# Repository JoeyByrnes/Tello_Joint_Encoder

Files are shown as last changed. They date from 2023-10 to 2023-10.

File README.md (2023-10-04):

# Tello_Joint_Encoder
PCB Design Files and Firmware for Tello Joint Encoders

<p align="center">
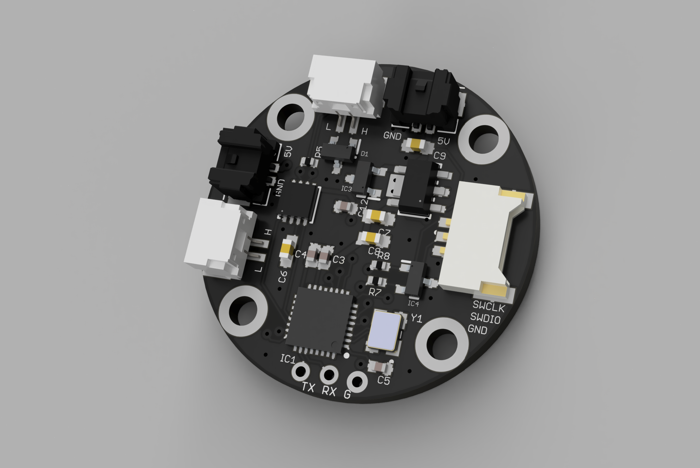
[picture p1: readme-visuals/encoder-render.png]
  
</p>
<p align="center">
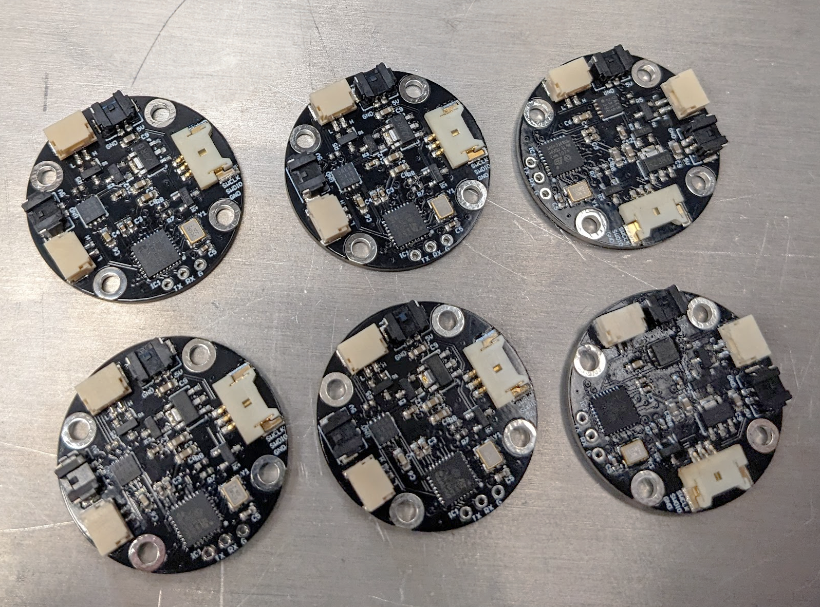
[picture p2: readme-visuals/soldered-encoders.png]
  
</p>
<p align="center">
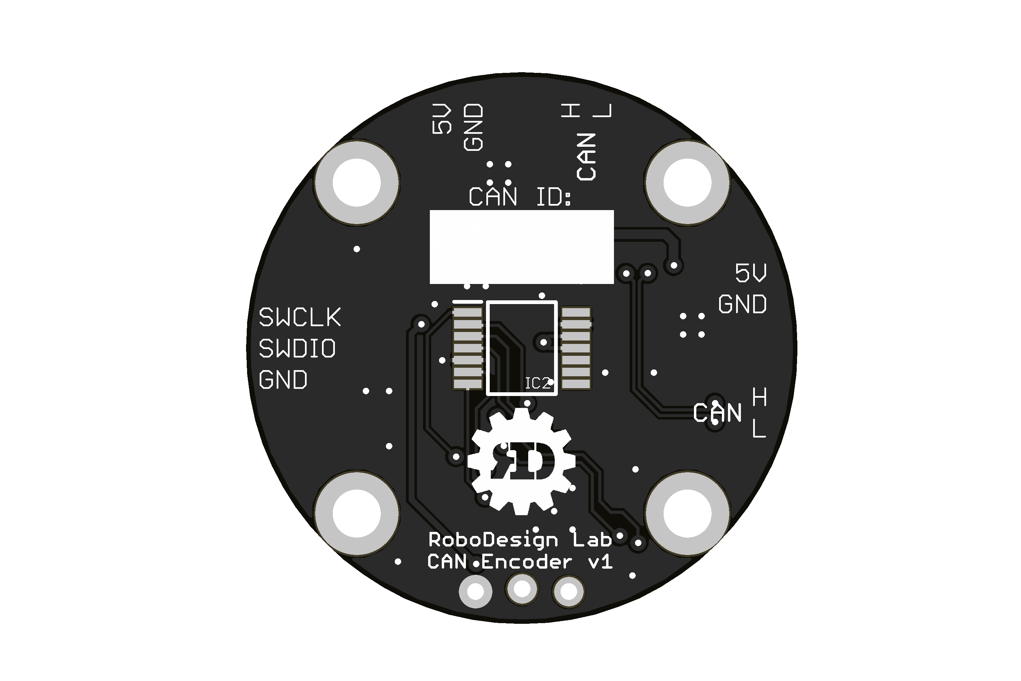
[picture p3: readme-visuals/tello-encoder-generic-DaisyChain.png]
  
</p>
<p align="center">
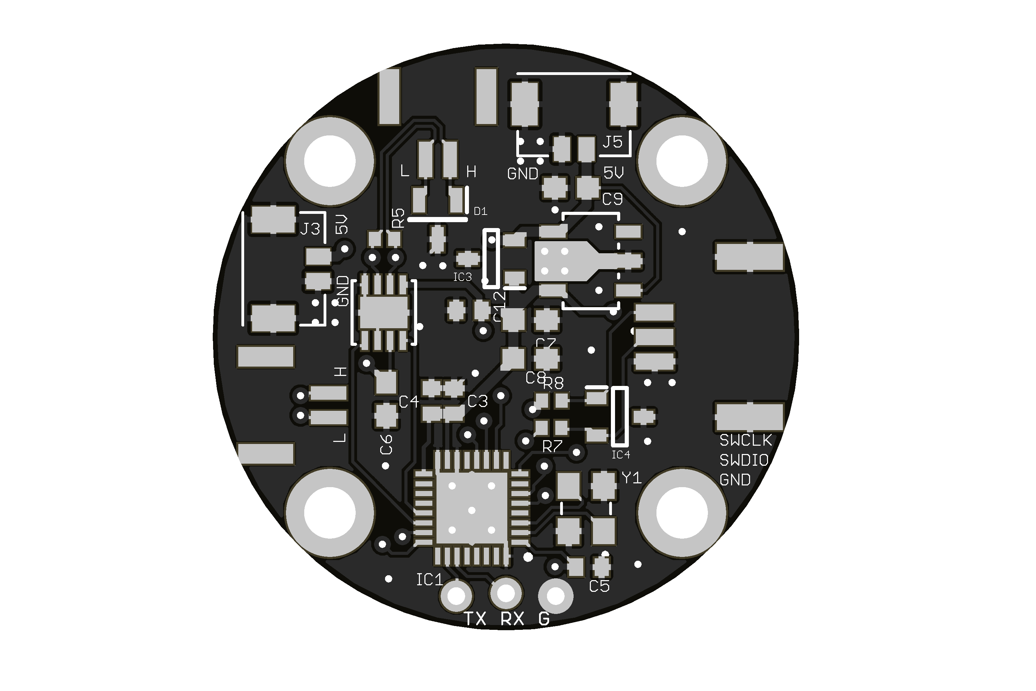
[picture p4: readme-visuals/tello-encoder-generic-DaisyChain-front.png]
  
</p>
<p align="center">
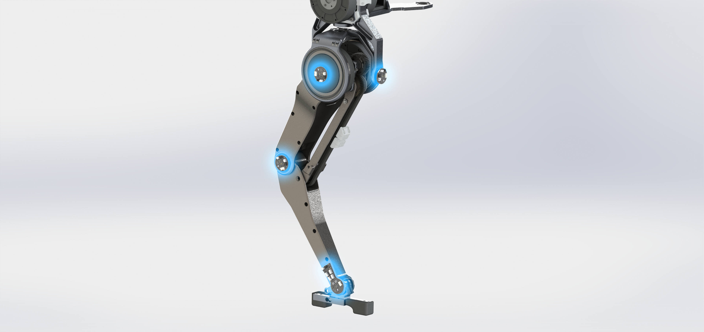
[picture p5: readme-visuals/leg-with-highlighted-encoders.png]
  
</p>

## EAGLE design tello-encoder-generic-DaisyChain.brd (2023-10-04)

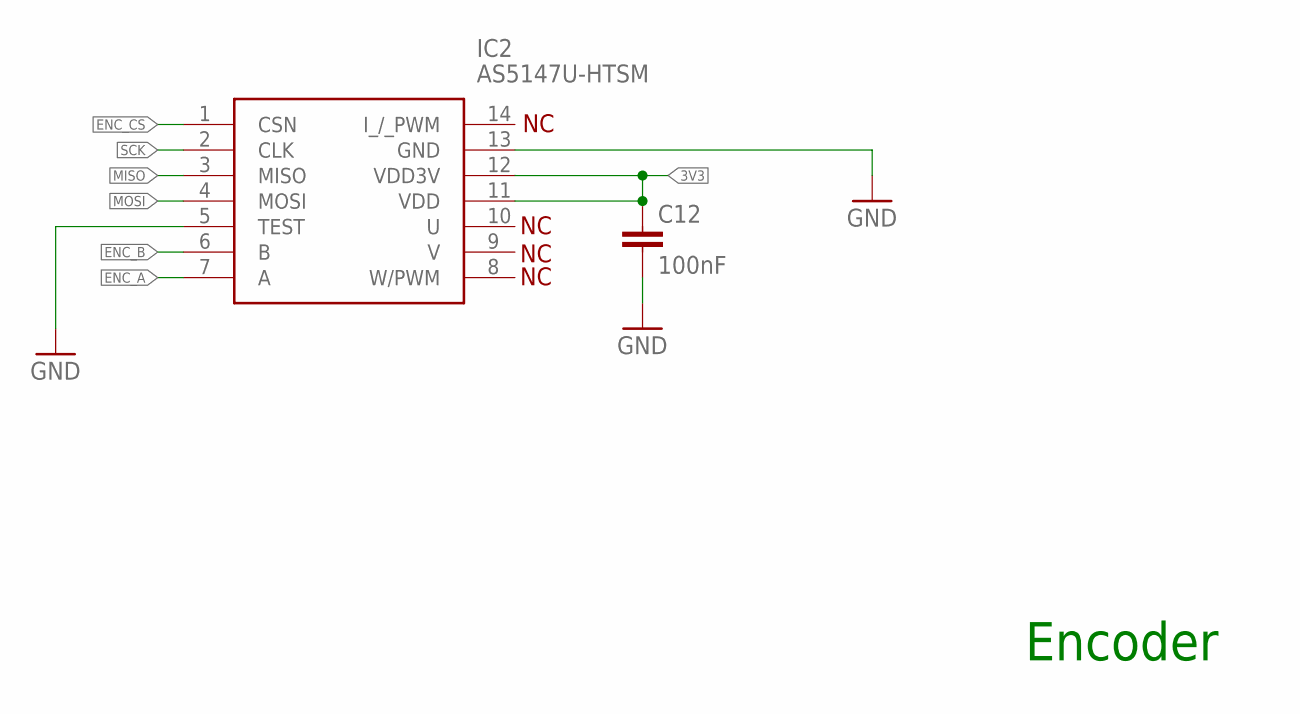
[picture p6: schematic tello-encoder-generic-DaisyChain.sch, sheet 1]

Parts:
C12: 100nF; C0402
IC2: AS5147U-HTSM; SOP65P640X120-14N

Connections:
3V3: C12.1, IC2.11 (VDD), IC2.12 (VDD3V); also elsewhere on the board
ENC_A: IC2.7 (A); also elsewhere on the board
ENC_B: IC2.6 (B); also elsewhere on the board
ENC_CS: IC2.1 (CSN); also elsewhere on the board
GND: C12.2, IC2.5 (TEST), IC2.13 (GND); also elsewhere on the board
MISO: IC2.3 (MISO); also elsewhere on the board
MOSI: IC2.4 (MOSI); also elsewhere on the board
SCK: IC2.2 (CLK); also elsewhere on the board

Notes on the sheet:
Encoder

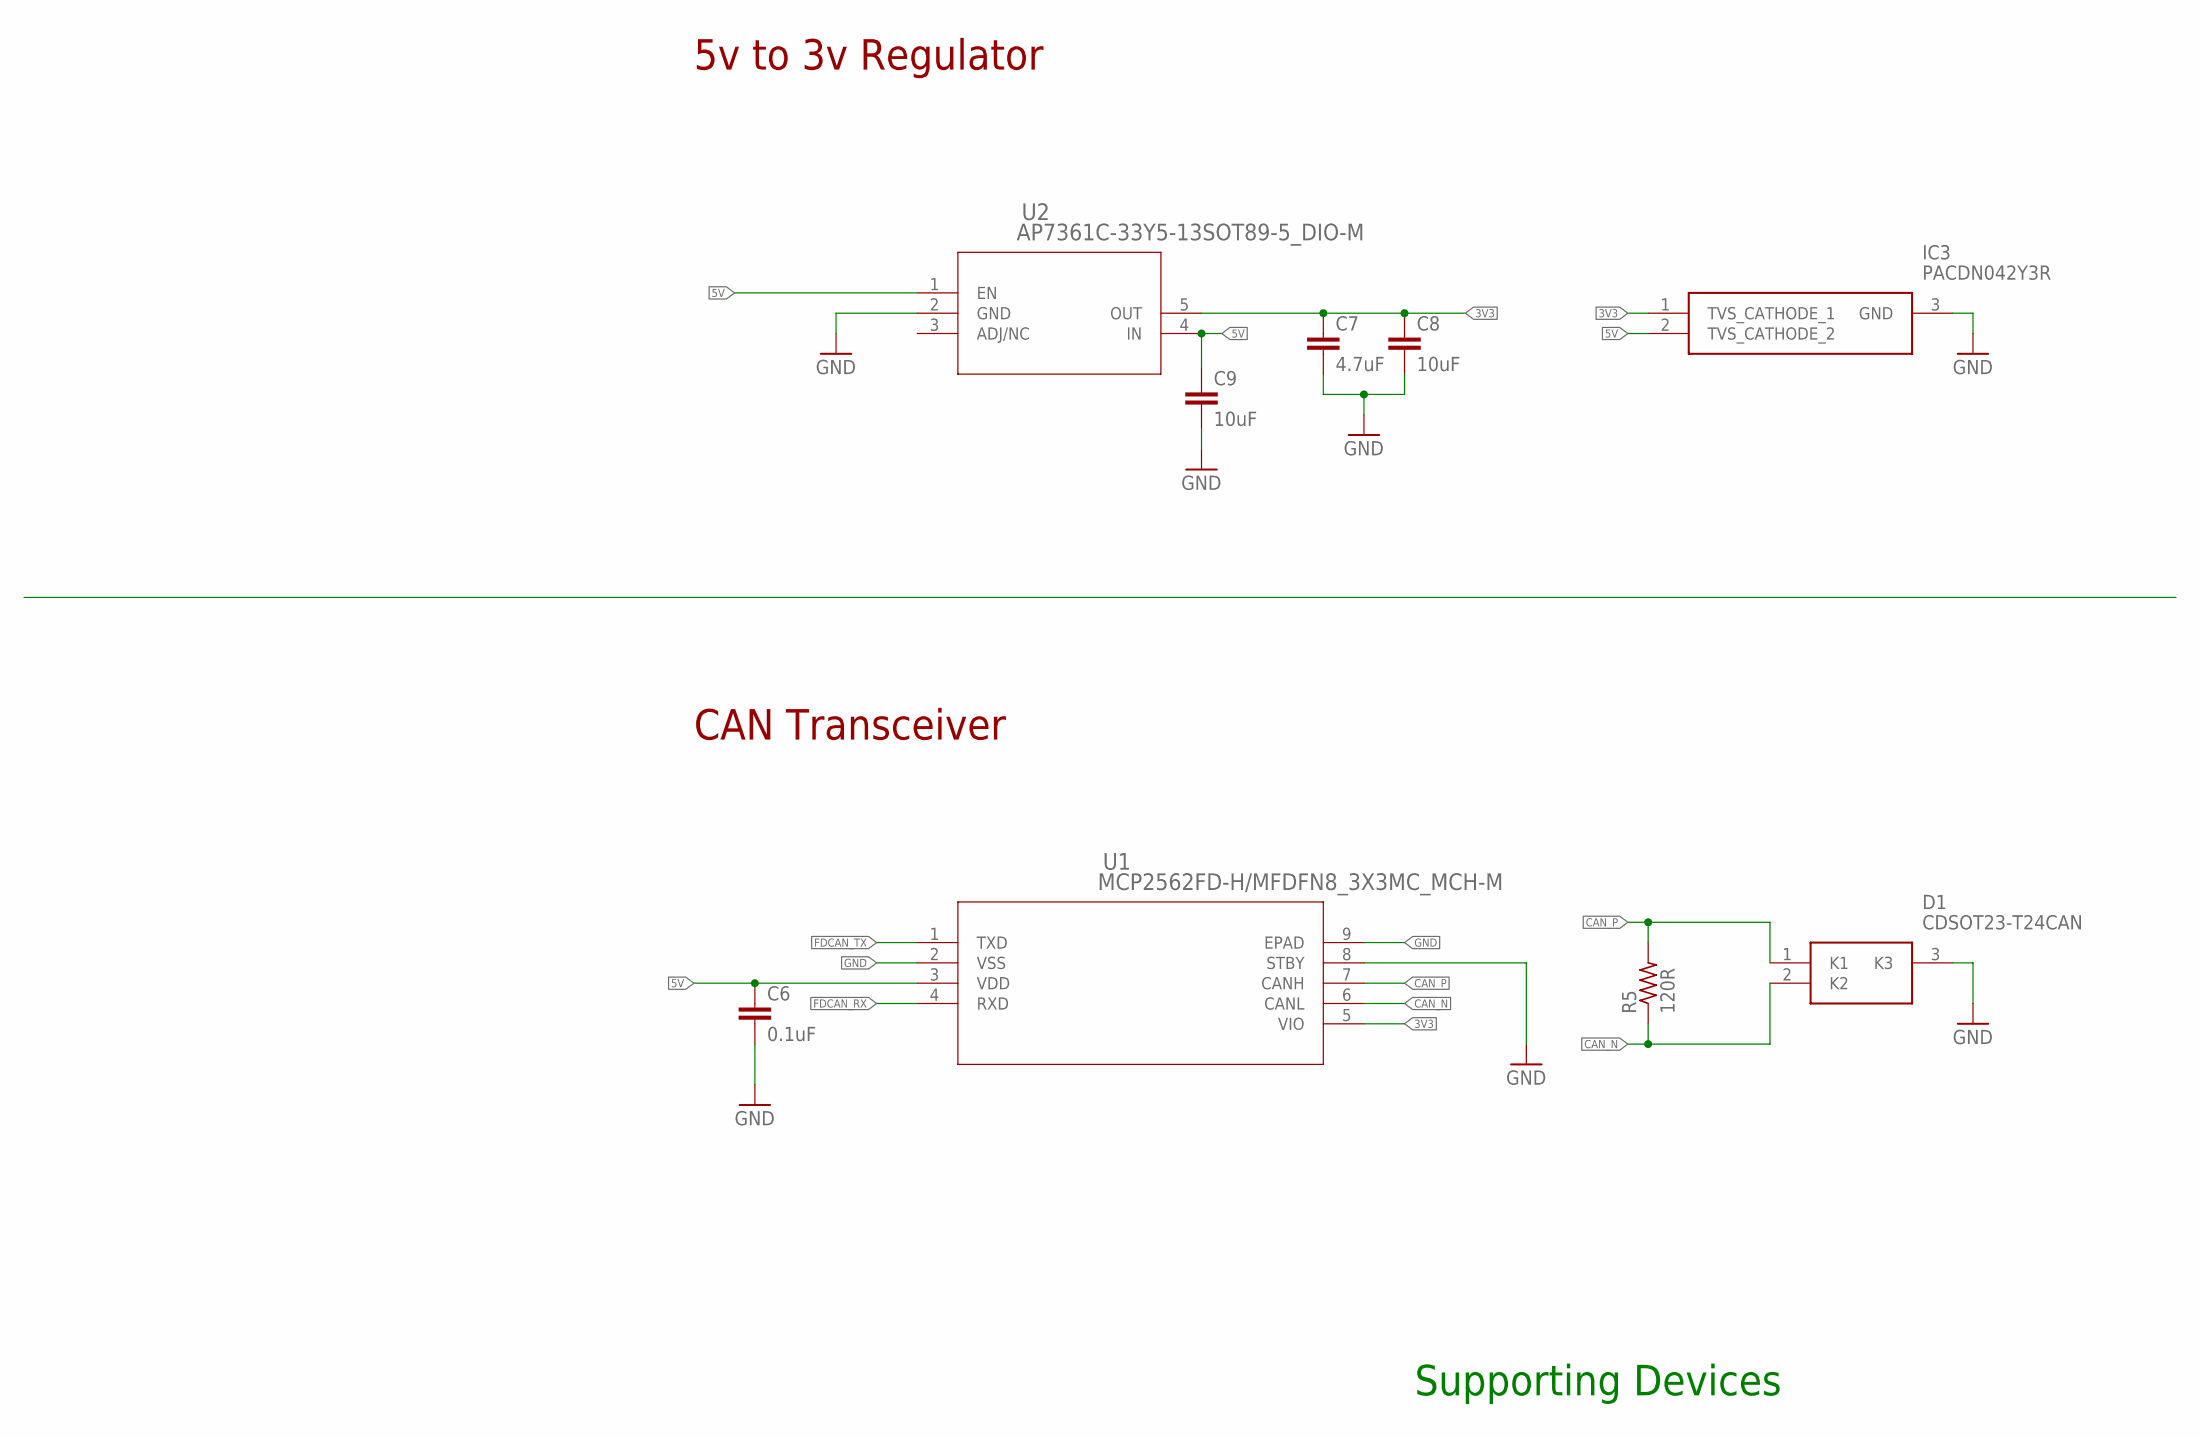
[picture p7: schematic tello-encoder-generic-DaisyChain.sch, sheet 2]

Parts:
C6: 0.1uF; C0603
C7: 4.7uF; C0603
C8, C9: 10uF; C0603
D1: CDSOT23-T24CAN; SOT95P230X117-3N
IC3: PACDN042Y3R; SOT96P237X111-3N
R5: 120R; R0402
U1: MCP2562FD-H/MFDFN8_3X3MC_MCH-M; DFN8_3X3MC_MCH-M
U2: AP7361C-33Y5-13SOT89-5_DIO-M; SOT89-5_DIO-M

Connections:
3V3: C7.1, C8.1, IC3.1 (TVS_CATHODE_1), U1.5 (VIO), U2.5 (OUT); also elsewhere on the board
5V: C6.1, C9.1, IC3.2 (TVS_CATHODE_2), U1.3 (VDD), U2.1 (EN), U2.4 (IN); also elsewhere on the board
CAN_N: D1.2 (K2), R5.1, U1.6 (CANL); also elsewhere on the board
CAN_P: D1.1 (K1), R5.2, U1.7 (CANH); also elsewhere on the board
FDCAN_RX: U1.4 (RXD); also elsewhere on the board
FDCAN_TX: U1.1 (TXD); also elsewhere on the board
GND: C6.2, C7.2, C8.2, C9.2, D1.3 (K3), IC3.3 (GND), U1.2 (VSS), U1.8 (STBY), U1.9 (EPAD), U2.2 (GND); also elsewhere on the board

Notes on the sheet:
5v to 3v Regulator
CAN Transceiver
Supporting Devices

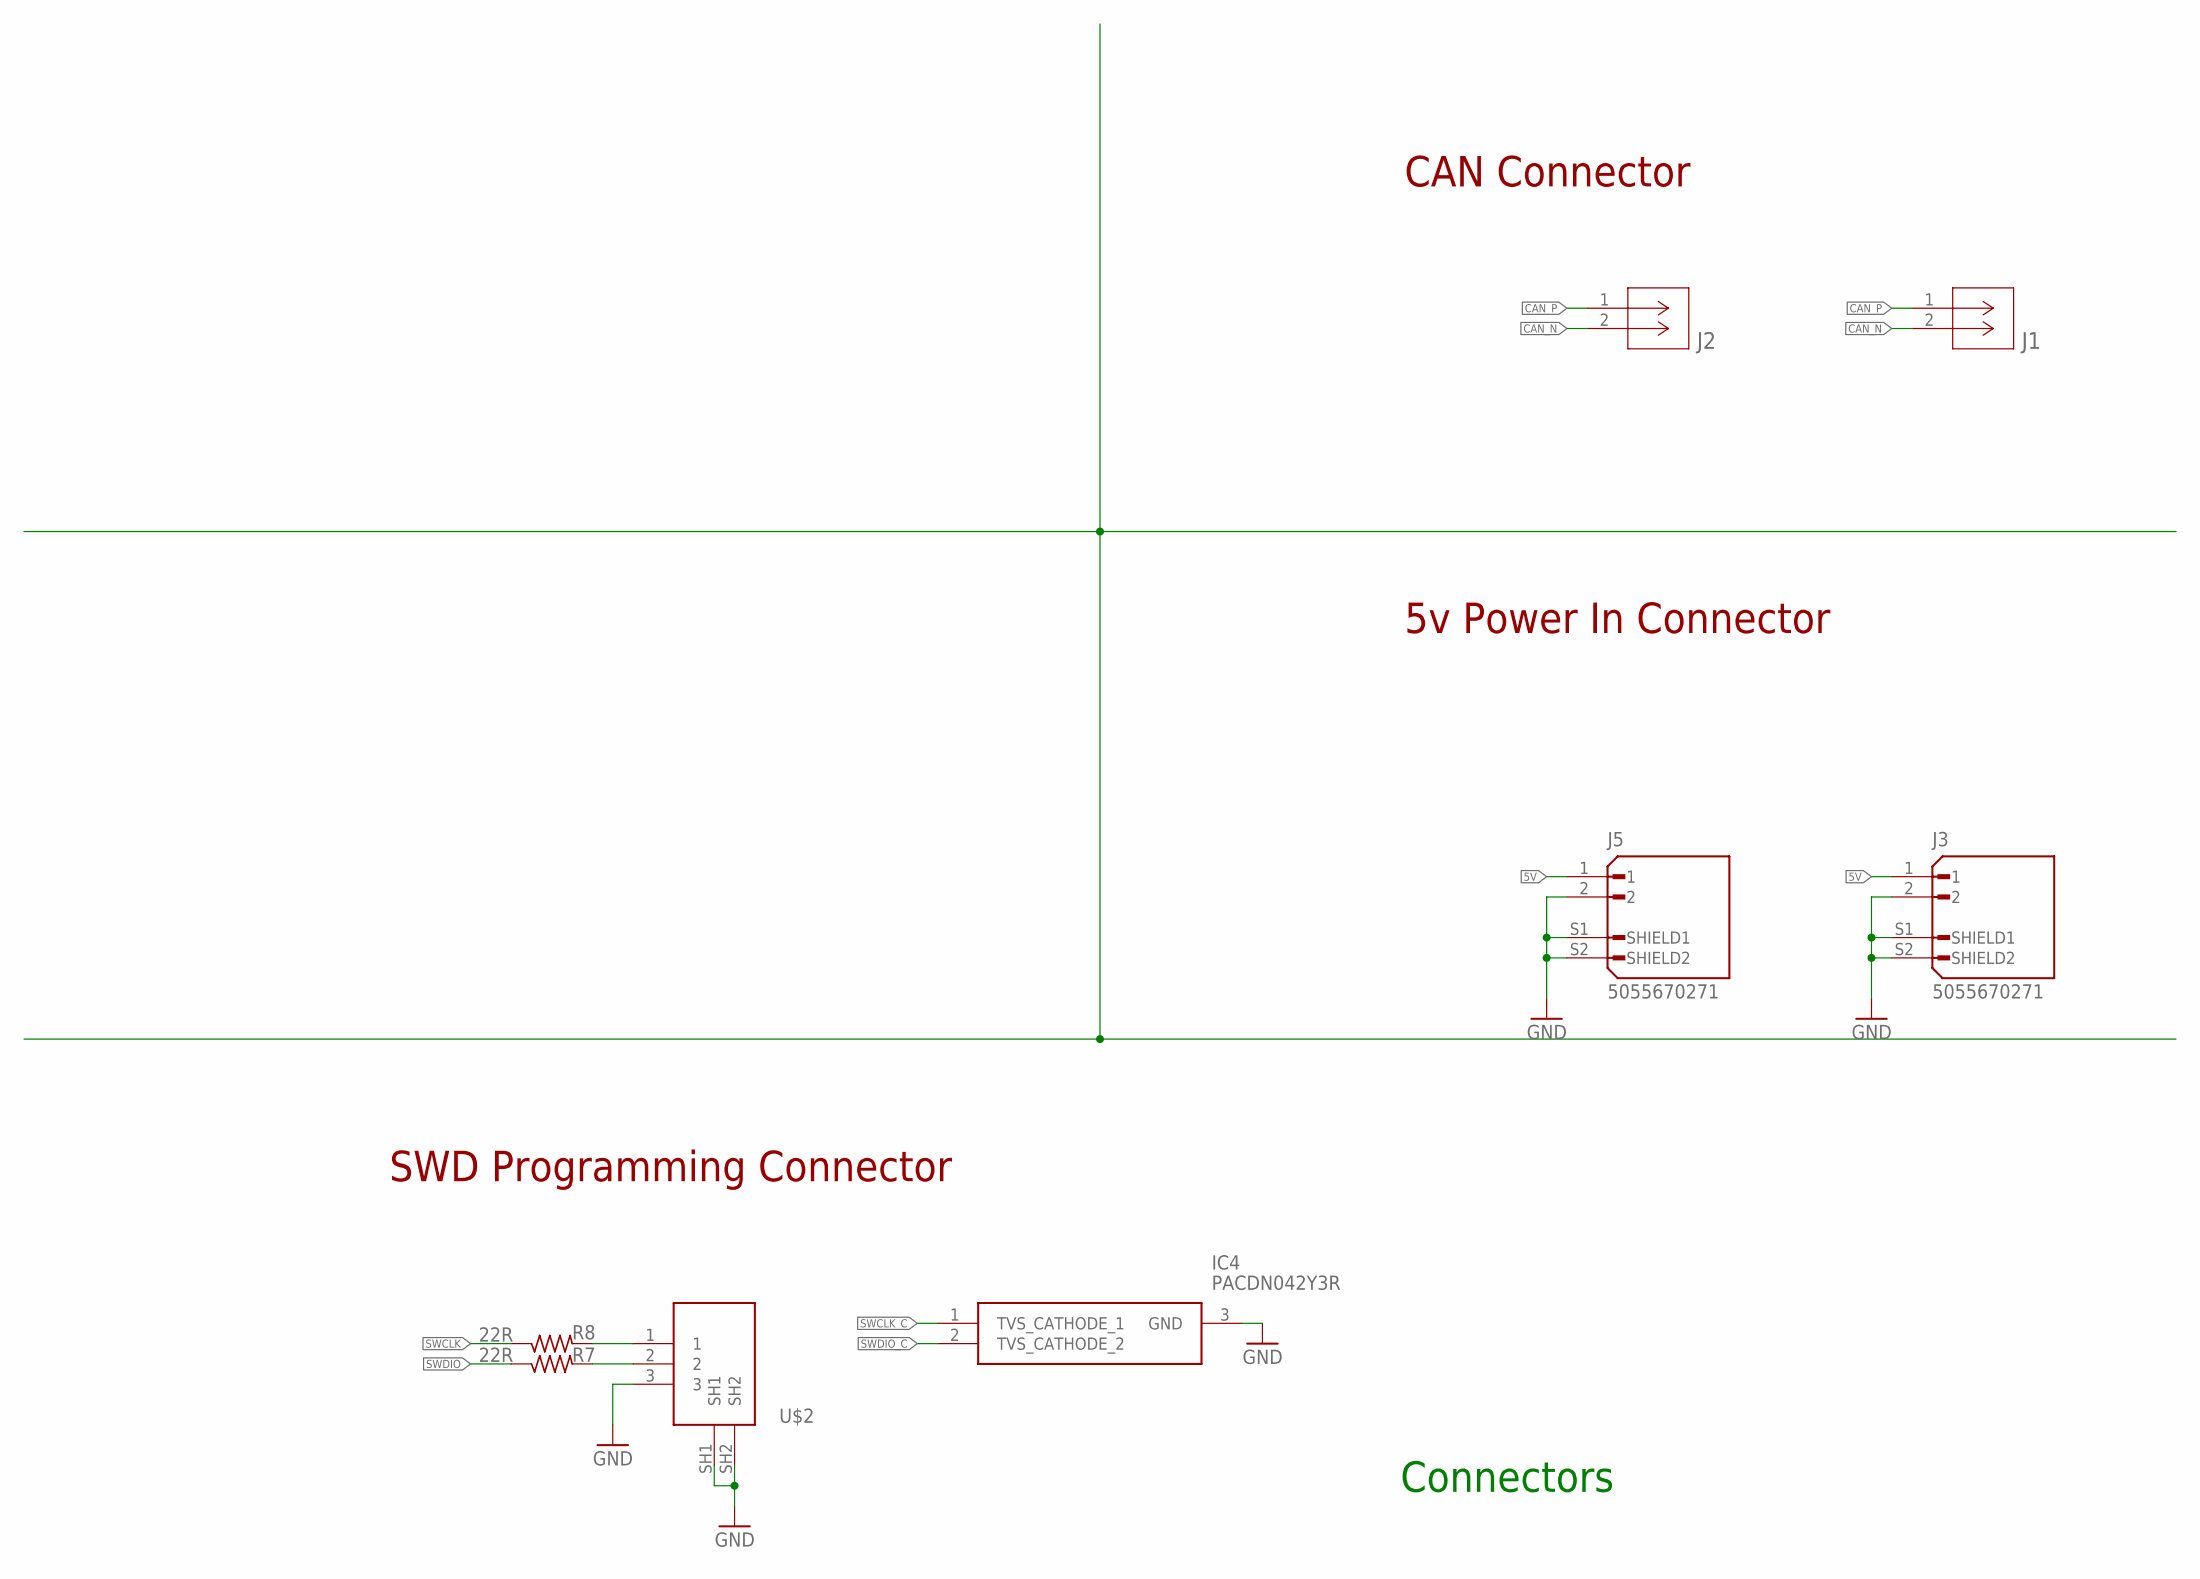
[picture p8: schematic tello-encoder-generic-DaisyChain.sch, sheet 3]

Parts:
IC4: PACDN042Y3R; SOT96P237X111-3N
J1, J2: SM02BGHSTBLFSN; CONN_SM02BGHSTB_JST
J3, J5: 5055670271; MOLEX_5055670271
R7, R8: 22R; R0402
U$2: 125SH-G-03-TR-SMT

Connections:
5V: J3.1, J5.1; also elsewhere on the board
CAN_N: J1.2, J2.2; also elsewhere on the board
CAN_P: J1.1, J2.1; also elsewhere on the board
GND: IC4.3 (GND), J3.2, J3.S1 (SHIELD1), J3.S2 (SHIELD2), J5.2, J5.S1 (SHIELD1), J5.S2 (SHIELD2), U$2.3, U$2.SH1, U$2.SH2; also elsewhere on the board
SWCLK: R8.1; also elsewhere on the board
SWCLK_C: IC4.1 (TVS_CATHODE_1), R8.2, U$2.1
SWDIO: R7.1; also elsewhere on the board
SWDIO_C: IC4.2 (TVS_CATHODE_2), R7.2, U$2.2

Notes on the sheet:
U$2
CAN Connector
5v Power In Connector
SWD Programming Connector
Connectors

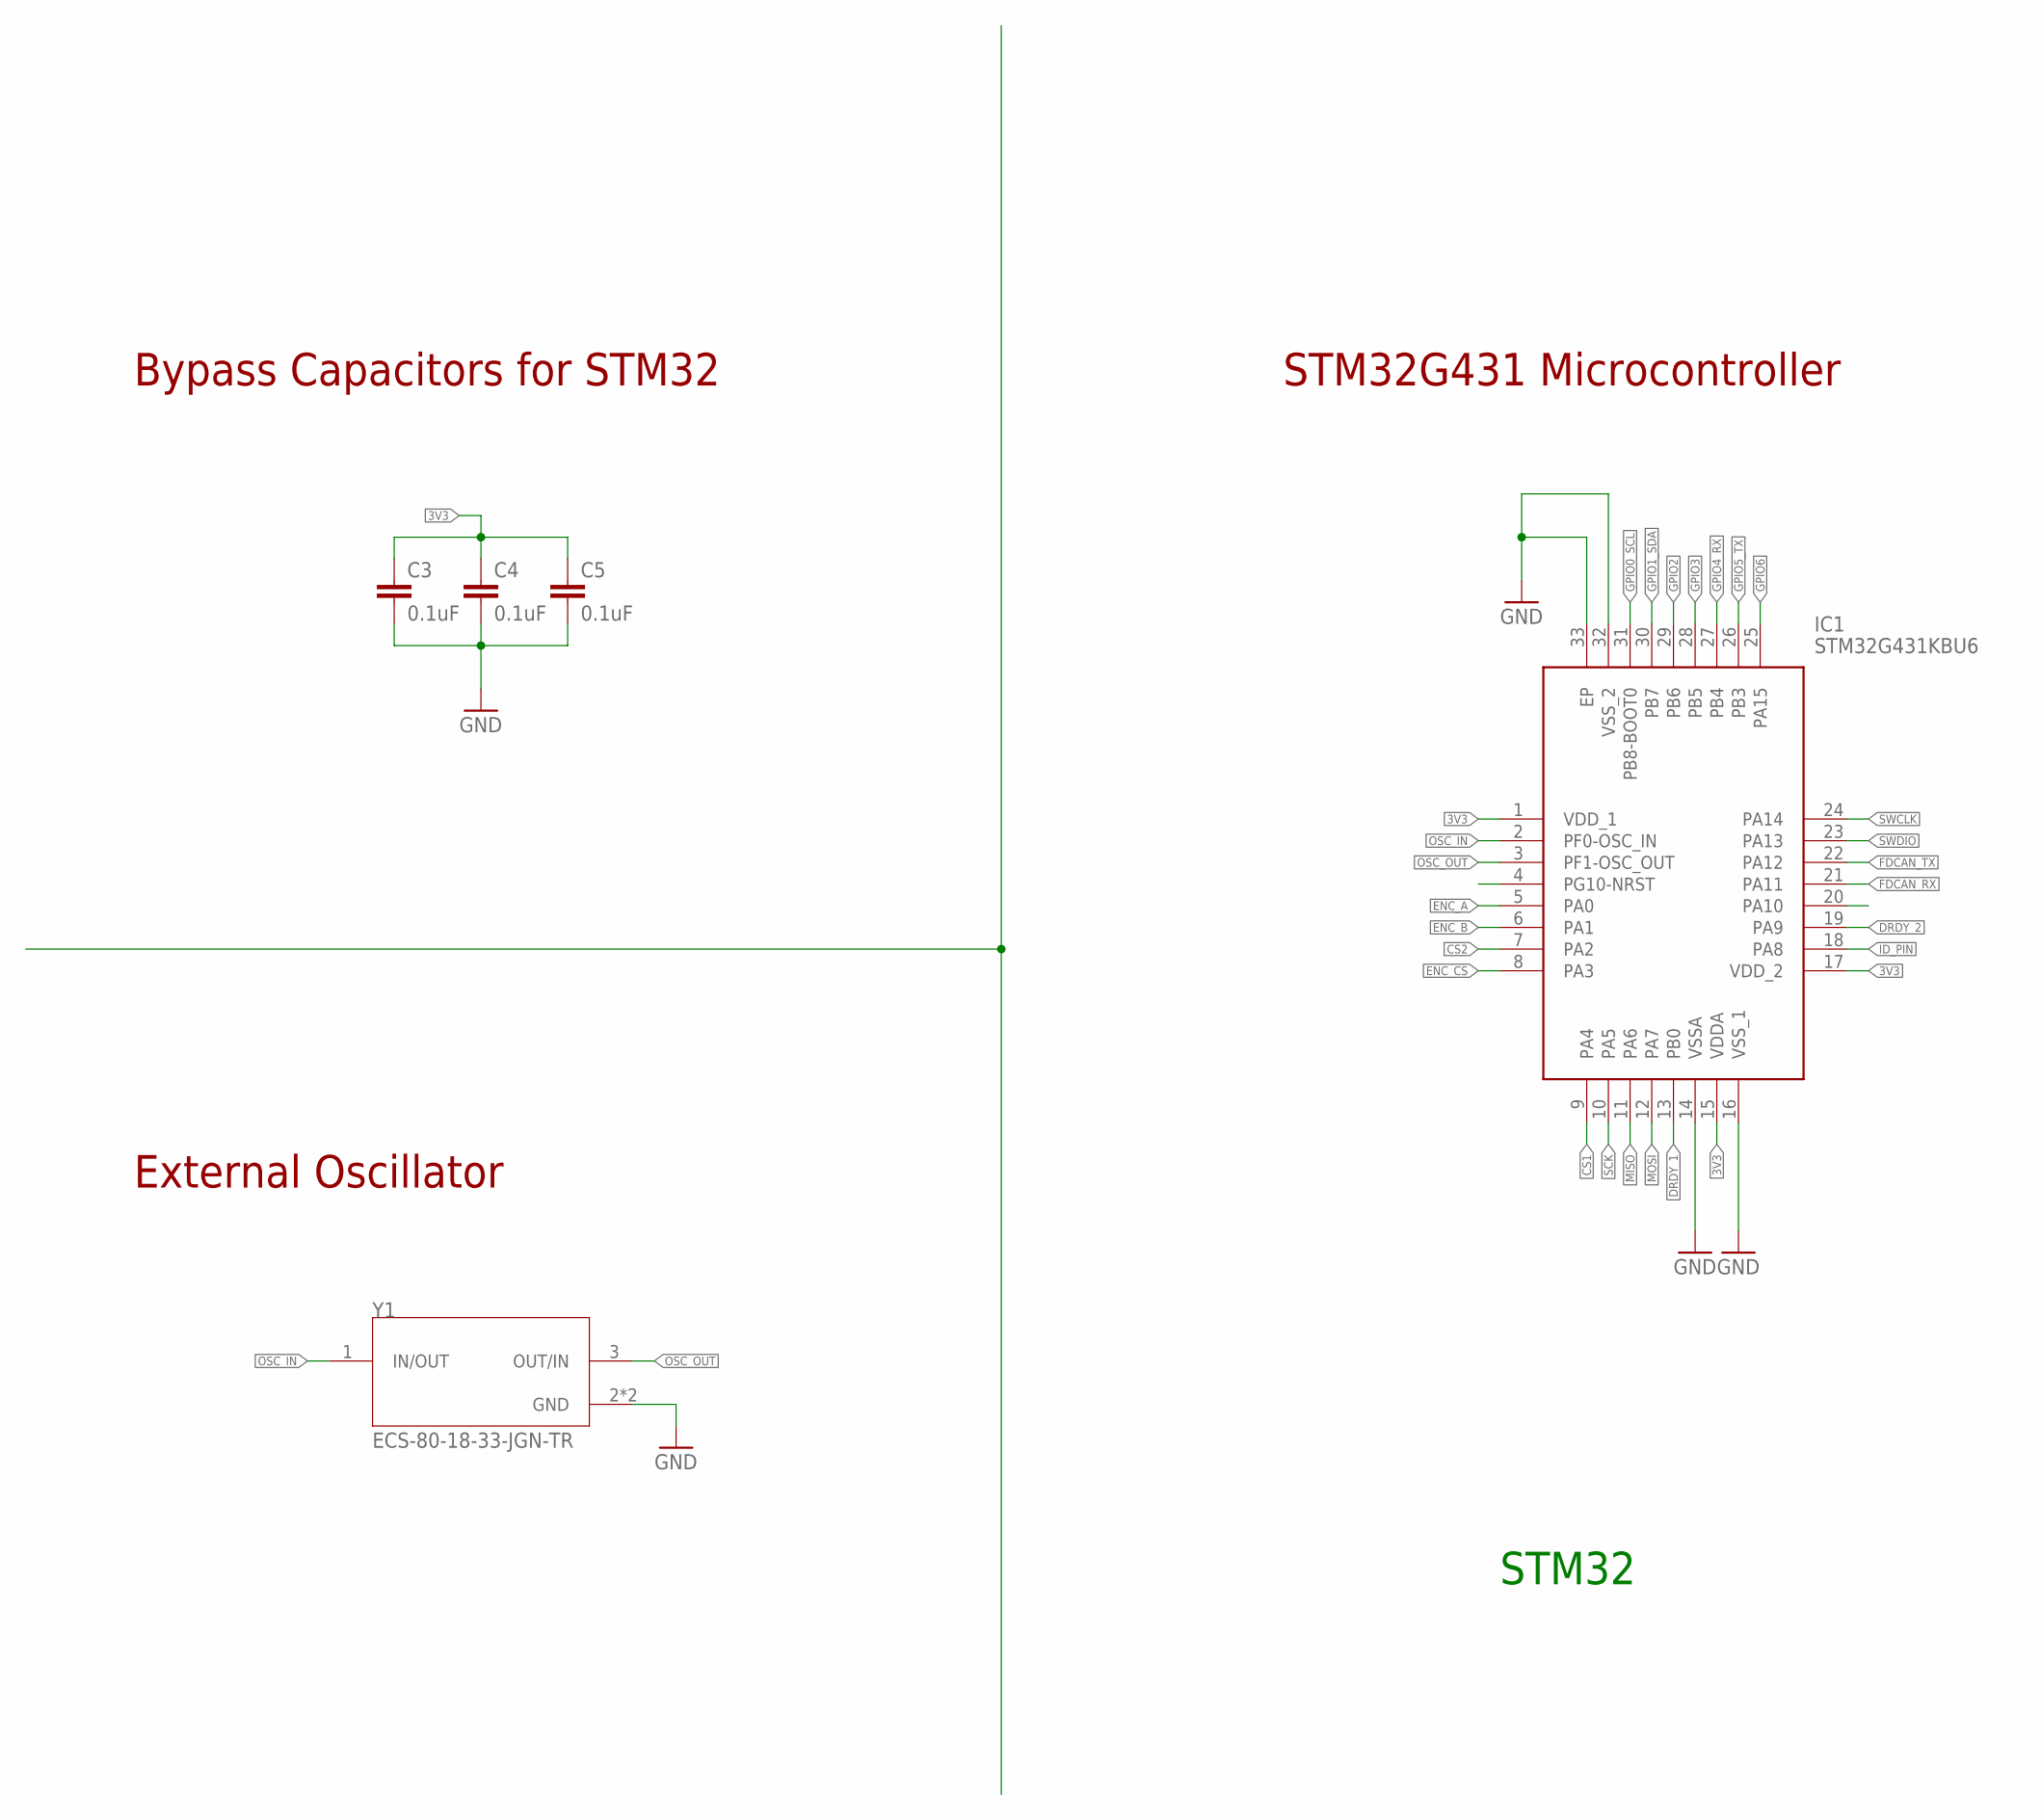
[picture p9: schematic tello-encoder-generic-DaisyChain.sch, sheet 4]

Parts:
C3, C4, C5: 0.1uF; C0402
IC1: STM32G431KBU6; QFN50P500X500X60-33N
Y1: ECS-80-18-33-JGN-TR; XTAL_ECS-240-8-33-AGN-TR

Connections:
3V3: C3.1, C4.1, C5.1, IC1.1 (VDD_1), IC1.15 (VDDA), IC1.17 (VDD_2); also elsewhere on the board
CS1: IC1.9 (PA4)
CS2: IC1.7 (PA2)
DRDY_1: IC1.13 (PB0)
DRDY_2: IC1.19 (PA9)
ENC_A: IC1.5 (PA0); also elsewhere on the board
ENC_B: IC1.6 (PA1); also elsewhere on the board
ENC_CS: IC1.8 (PA3); also elsewhere on the board
FDCAN_RX: IC1.21 (PA11); also elsewhere on the board
FDCAN_TX: IC1.22 (PA12); also elsewhere on the board
GND: C3.2, C4.2, C5.2, IC1.14 (VSSA), IC1.16 (VSS_1), IC1.32 (VSS_2), IC1.33 (EP), Y1.2 (GND), Y1.4 (GND); also elsewhere on the board
GPIO0_SCL: IC1.31 (PB8-BOOT0)
GPIO1_SDA: IC1.30 (PB7)
GPIO2: IC1.29 (PB6)
GPIO3: IC1.28 (PB5)
GPIO4_RX: IC1.27 (PB4)
GPIO5_TX: IC1.26 (PB3)
GPIO6: IC1.25 (PA15)
ID_PIN: IC1.18 (PA8)
MISO: IC1.11 (PA6); also elsewhere on the board
MOSI: IC1.12 (PA7); also elsewhere on the board
OSC_IN: IC1.2 (PF0-OSC_IN), Y1.1 (IN/OUT)
OSC_OUT: IC1.3 (PF1-OSC_OUT), Y1.3 (OUT/IN)
SCK: IC1.10 (PA5); also elsewhere on the board
SWCLK: IC1.24 (PA14); also elsewhere on the board
SWDIO: IC1.23 (PA13); also elsewhere on the board

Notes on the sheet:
Bypass Capacitors for STM32
External Oscillator
STM32G431 Microcontroller
STM32

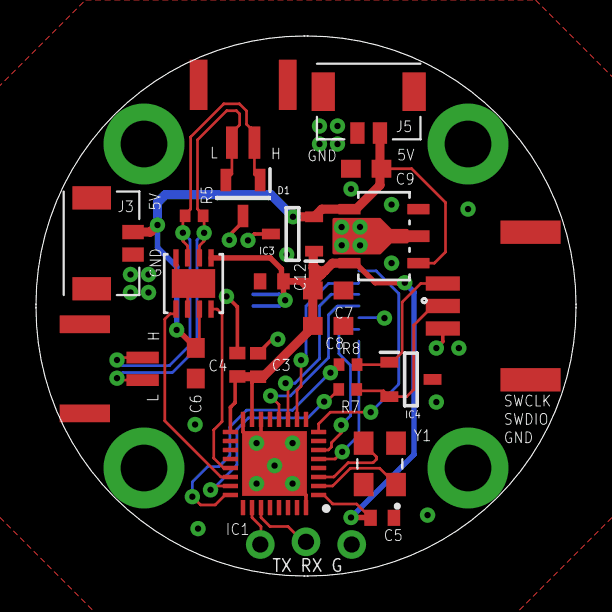
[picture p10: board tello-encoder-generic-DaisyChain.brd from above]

Board: 4 copper layers, 30.0 x 30.0 mm, 24 parts (1 on the bottom side), 19 nets.

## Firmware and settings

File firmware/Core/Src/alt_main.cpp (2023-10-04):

#include <dwt_delay.hpp>
#include "alt_main.h"
#include "stm32g4xx_hal.h"
#include <Protocentral_ADS1220.hpp>
#include <string.h>
#include <stdio.h>
#include "main.h"
#include <math.h>

#define CPU_FREQ_HZ (float)170e6

#define AS4047D_CS1_Port GPIOA
#define AS4047D_CS1_Pin GPIO_PIN_3
#define ENC_CS_HIGH AS4047D_CS1_Port->BSRR=(uint32_t)AS4047D_CS1_Pin
#define ENC_CS_LOW AS4047D_CS1_Port->BRR=(uint32_t)AS4047D_CS1_Pin
#define READ_POS_REG 0xFFFF
#define READ_POS_REG_COMP 0xFFFE
#define READ_VEL_REG 0xFFFC

#define HALF_ENC_CPR 8192

//#define CAN_DEVICE_ID_ENC (THIS IS UNUSED NOW, ID is read from FLASH)
#define CAN_DEVICE_ID_ENC_ADDRESS ((uint8_t*)0x0800FFF0)
#define CAN_MASTER_ID (uint8_t)0
#define CAN_DATA_SIZE 8    // Number of data bytes in a CAN packet

uint8_t encoder_packet[8]; // Packet 1 with 8 bytes

FDCAN_TxHeaderTypeDef txHeader;

uint8_t can_id = 0;

uint16_t last_raw_pos = 0;
int num_turns = 0;

union FloatToBytes {
    float f;
    uint8_t b[sizeof(float)];
};

union Int32ToBytes {
    int32_t i;
    uint8_t b[sizeof(int32_t)];
};

union Int16ToBytes {
    int16_t i;
    uint8_t b[sizeof(int16_t)];
};


bool first_reading = true;

extern UART_HandleTypeDef huart2;

extern SPI_HandleTypeDef hspi1;

extern DMA_HandleTypeDef hdma_usart2_tx;

extern FDCAN_HandleTypeDef hfdcan1;


uint16_t AS5147_Read_Pos()
{
	ENC_CS_LOW;
	while ((SPI1->SR & SPI_SR_BSY) != 0);
	SPI1->DR = READ_POS_REG;
	SPI1->CR1 |= SPI_CR1_SPE;
	while ((SPI1->SR & SPI_SR_RXNE) == 0);
	uint16_t result = SPI1->DR;
	while ((SPI1->SR & SPI_SR_TXE) == 0);
	while ((SPI1->SR & SPI_SR_BSY) != 0);
	SPI1->CR1 &= ~(SPI_CR1_SPE);
	ENC_CS_HIGH;
	return (result & 0x3FFF);
}

uint16_t AS5147_Read_Vel()
{
	ENC_CS_LOW;
	while ((SPI1->SR & SPI_SR_BSY) != 0);
	SPI1->DR = READ_VEL_REG;
	SPI1->CR1 |= SPI_CR1_SPE;
	while ((SPI1->SR & SPI_SR_RXNE) == 0);
	uint16_t result = SPI1->DR;
	while ((SPI1->SR & SPI_SR_TXE) == 0);
	while ((SPI1->SR & SPI_SR_BSY) != 0);
	SPI1->CR1 &= ~(SPI_CR1_SPE);
	ENC_CS_HIGH;
	return (result & 0x3FFF);
}

int32_t twoscomp14bit_to_int(int16_t value) {
    // Extract the sign bit from the 14-bit number (bit 13)
    int32_t sign_bit = (value & 0x2000) ? 0xFFFFC000 : 0x00000000;

    // Extend the 14-bit number to 32 bits while preserving its sign
    int32_t result = (int32_t)(value | sign_bit);

    return result;
}


int alt_main()
{
	/* Initialization */
	can_id = *(CAN_DEVICE_ID_ENC_ADDRESS);

	txHeader.Identifier = (can_id-20); // will set master IDs to 0 through 9 to avoid conflicts
	txHeader.IdType = FDCAN_STANDARD_ID;
	txHeader.TxFrameType = FDCAN_DATA_FRAME;
	txHeader.DataLength = FDCAN_DLC_BYTES_8;
	txHeader.ErrorStateIndicator = FDCAN_ESI_ACTIVE;
	txHeader.BitRateSwitch = FDCAN_BRS_OFF;
	txHeader.FDFormat = FDCAN_CLASSIC_CAN;
	txHeader.TxEventFifoControl = FDCAN_NO_TX_EVENTS;
	txHeader.MessageMarker = 0;

	last_raw_pos = AS5147_Read_Pos();



	while (1)
	{


	}
}

int serial_cnt = 0;

void setSPIMode(int mode)
{
	SPI1->CR1 &= ~SPI_CR1_SPE;
	if(mode == 1){
		// Set CPOL and CPHA bits to configure SPI mode 1
		SPI1->CR1 &= ~SPI_CR1_CPOL;  // Clear CPOL bit (CPOL = 0)
		SPI1->CR1 |= SPI_CR1_CPHA;   // Set CPHA bit  (CPHA = 1)
	}
	else if(mode == 0){
		// Set CPOL and CPHA bits to configure SPI mode 1
		SPI1->CR1 &= ~SPI_CR1_CPOL;  // Clear CPOL bit (CPOL = 0)
		SPI1->CR1 &= ~SPI_CR1_CPHA;   // Set CPHA bit  (CPHA = 0)
	}
	SPI1->CR1 |= SPI_CR1_SPE;
}

void main_1KHz_interrupt()
{

	int multiturn_pos;

	AS5147_Read_Pos();
	AS5147_Read_Pos();
	uint16_t pos = AS5147_Read_Pos();

	int rollover = 0;
	int angle_diff = pos - last_raw_pos;
	if(angle_diff > HALF_ENC_CPR){rollover = -1;}
	else if(angle_diff < -HALF_ENC_CPR){rollover = 1;}
	num_turns += rollover;

	/* Multi-turn position */
	multiturn_pos = pos + 16384*num_turns;

	last_raw_pos = pos;

	AS5147_Read_Vel();
	AS5147_Read_Vel();
	uint16_t velEnc = AS5147_Read_Vel();


	int velInt = twoscomp14bit_to_int(velEnc);


//	FloatToBytes velf2b;
//	velf2b.f = velocity;
	Int32ToBytes int2b;
	int2b.i = velInt;

	// ================================================================================================

	txHeader.DataLength = FDCAN_DLC_BYTES_8;

	encoder_packet[0] = can_id;
	encoder_packet[1] = (pos >> 8) & 0xFF;
	encoder_packet[2] = (pos) & 0xFF;
	encoder_packet[3] = (127+num_turns) &0xFF; // turn tracking only supported up to 127 turns
	encoder_packet[4] = int2b.b[3];
	encoder_packet[5] = int2b.b[2];
	encoder_packet[6] = int2b.b[1];
	encoder_packet[7] = int2b.b[0];

	HAL_FDCAN_AddMessageToTxFifoQ(&hfdcan1, &txHeader, encoder_packet);
	usleep(200);

	char uartTxBuffer[1024];

	if(serial_cnt%100 == 0){
		sprintf(uartTxBuffer, "multiturn: %d,      velocity: %d    \r\n", multiturn_pos, velInt);
		HAL_UART_Transmit(&huart2, (uint8_t *)uartTxBuffer, strlen(uartTxBuffer),1);
	}
	serial_cnt++;


}

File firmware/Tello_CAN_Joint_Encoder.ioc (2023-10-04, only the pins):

Mcu.UserName=STM32G431KBUx
PA11.Signal=FDCAN1_RX
PA12.Signal=FDCAN1_TX
PA13.Signal=SYS_JTMS-SWDIO
PA14.Signal=SYS_JTCK-SWCLK
PA15.Signal=GPIO_Output
PA2.Signal=GPIO_Output
PA3.Signal=GPIO_Output
PA4.Signal=GPIO_Output
PA5.Signal=SPI1_SCK
PA6.Signal=SPI1_MISO
PA7.Signal=SPI1_MOSI
PB0.Signal=GPIO_Input
PB3.Signal=USART2_TX
PB4.Signal=USART2_RX
PB5.Signal=GPIO_Output
PB6.Signal=GPIO_Output

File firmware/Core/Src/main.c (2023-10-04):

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
/* Includes ------------------------------------------------------------------*/
#include "main.h"
#include "fdcan.h"
#include "spi.h"
#include "tim.h"
#include "usart.h"
#include "gpio.h"

/* USER CODE BEGIN Includes */
#include "alt_main.h"
#include "dwt_delay.hpp"
#include <string.h>
#include <stdio.h>
/* USER CODE END Includes */


void SystemClock_Config(void);
/* USER CODE BEGIN 0 */

void usleep(uint32_t us)
{
    // Clock cycles per microsecond for a 170MHz clock
    const uint32_t CYCLES_PER_MICROSECOND = 13; // ---> 170/13 (~13 clock cycles per operation)

    uint32_t totalCycles = us * CYCLES_PER_MICROSECOND;

    // Loop to execute the NOP instruction for the desired delay
    for (uint32_t i = 0; i < totalCycles; ++i)
    {
        asm volatile("NOP");
    }
}

/* USER CODE END 0 */

/**
  * @brief  The application entry point.
  * @retval int
  */
int main(void)
{
  /* MCU Configuration--------------------------------------------------------*/

  /* Reset of all peripherals, Initializes the Flash interface and the Systick. */
  HAL_Init();

  /* USER CODE BEGIN Init */
  for (uint32_t i = 0; i < 13*1000; ++i)
  {
	  asm volatile("NOP");
  }
  /* USER CODE END Init */

  /* Configure the system clock */
  SystemClock_Config();

  /* USER CODE BEGIN SysInit */
  HAL_Delay(2000);
  /* USER CODE END SysInit */

  /* Initialize all configured peripherals */
  MX_GPIO_Init();
  MX_FDCAN1_Init();
  MX_SPI1_Init();
  MX_TIM2_Init();
  MX_TIM1_Init();
  MX_USART2_UART_Init();
  /* USER CODE BEGIN 2 */

  DWT_Init();

  // Enable GPIOB clock
  __HAL_RCC_GPIOA_CLK_ENABLE();
  __HAL_RCC_GPIOB_CLK_ENABLE();

  // Configure PB6 as output
  GPIO_InitTypeDef GPIO_InitStruct;
  GPIO_InitStruct.Pin = GPIO_PIN_5 | GPIO_PIN_6;
  GPIO_InitStruct.Mode = GPIO_MODE_OUTPUT_PP;
  GPIO_InitStruct.Pull = GPIO_NOPULL;
  GPIO_InitStruct.Speed = GPIO_SPEED_FREQ_HIGH;
  HAL_GPIO_Init(GPIOB, &GPIO_InitStruct);

  // Set chip selects as outputs and initialize them to high
  GPIO_InitTypeDef GPIO_InitStruct2 = {0};
  GPIO_InitStruct2.Pin = GPIO_PIN_2 | GPIO_PIN_3 | GPIO_PIN_4;
  GPIO_InitStruct2.Mode = GPIO_MODE_OUTPUT_PP;
  GPIO_InitStruct2.Pull = GPIO_NOPULL;
  GPIO_InitStruct2.Speed = GPIO_SPEED_FREQ_HIGH;
  HAL_GPIO_Init(GPIOA, &GPIO_InitStruct2);

  // GPIOA Pin 9 (PA9) configuration as input
  GPIO_InitTypeDef GPIO_InitStruct3;
  GPIO_InitStruct3.Pin = GPIO_PIN_9;
  GPIO_InitStruct3.Mode = GPIO_MODE_INPUT;
  GPIO_InitStruct3.Pull = GPIO_NOPULL;
  HAL_GPIO_Init(GPIOA, &GPIO_InitStruct3);

  // GPIOA Pin 8 (PA8) configuration as input
  GPIO_InitStruct3.Pin = GPIO_PIN_8;
  HAL_GPIO_Init(GPIOA, &GPIO_InitStruct3);

  // GPIOB Pin 0 (PB0) configuration as input
  GPIO_InitStruct3.Pin = GPIO_PIN_0;
  HAL_GPIO_Init(GPIOB, &GPIO_InitStruct3);

  // Initialize chip selects to high
  HAL_GPIO_WritePin(GPIOA, GPIO_PIN_2, GPIO_PIN_SET);
  HAL_GPIO_WritePin(GPIOA, GPIO_PIN_3, GPIO_PIN_SET);
  HAL_GPIO_WritePin(GPIOA, GPIO_PIN_4, GPIO_PIN_SET);

  HAL_FDCAN_Start(&hfdcan1);
  // Start Timer 1
  HAL_TIM_Base_Start_IT(&htim1);

  /* USER CODE END 2 */

  /* Infinite loop */
  /* USER CODE BEGIN WHILE */
  char message[] = "Joint Encoder Program Started.\r\n";
  HAL_UART_Transmit(&huart2, (uint8_t *)message, strlen(message),1);
  alt_main();

  while (1)
  {

    /* USER CODE END WHILE */

    /* USER CODE BEGIN 3 */
  }
  /* USER CODE END 3 */
}

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

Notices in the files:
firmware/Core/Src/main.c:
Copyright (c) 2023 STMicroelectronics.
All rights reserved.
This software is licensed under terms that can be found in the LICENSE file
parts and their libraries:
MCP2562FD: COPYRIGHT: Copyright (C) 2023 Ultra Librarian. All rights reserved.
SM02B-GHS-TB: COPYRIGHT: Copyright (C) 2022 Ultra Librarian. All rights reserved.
